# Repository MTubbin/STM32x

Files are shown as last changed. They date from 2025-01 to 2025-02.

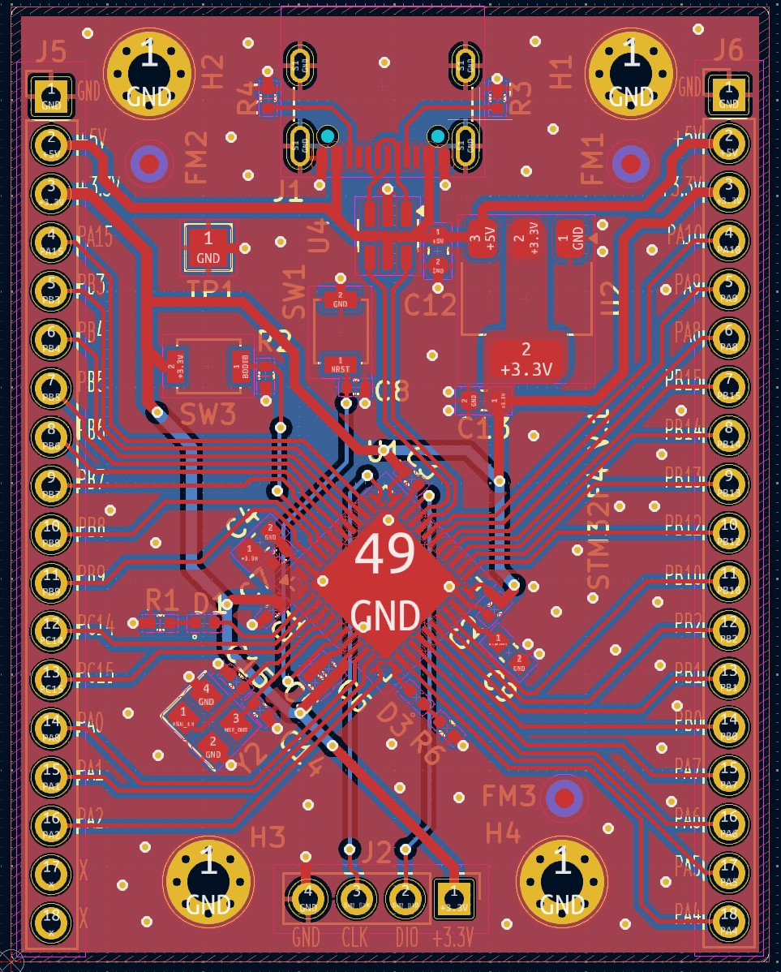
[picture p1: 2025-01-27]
Hardware/Photos/STM32_2Layer.jpg

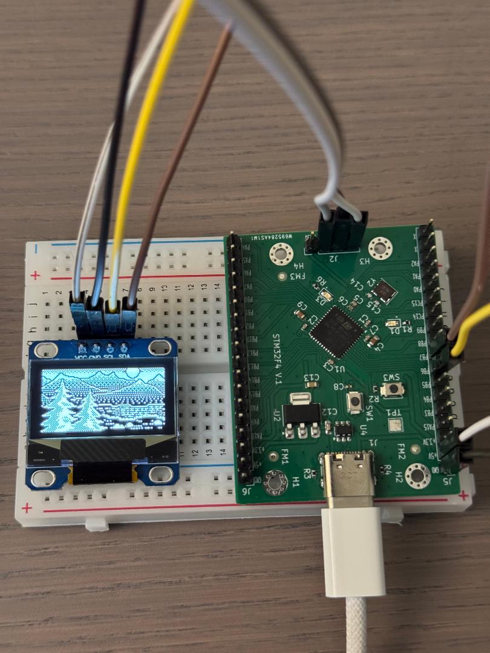
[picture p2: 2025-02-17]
Hardware/Photos/display.jpg

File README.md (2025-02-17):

# STM32x
Repo for custom STM32F4 Breakout board 

Directory:

Hardware folder - PCB Schematic, board layout
  - Photos: Schematic, PCB, and Board Photos

Software folder - current main and display txt files

STM32 Board

display

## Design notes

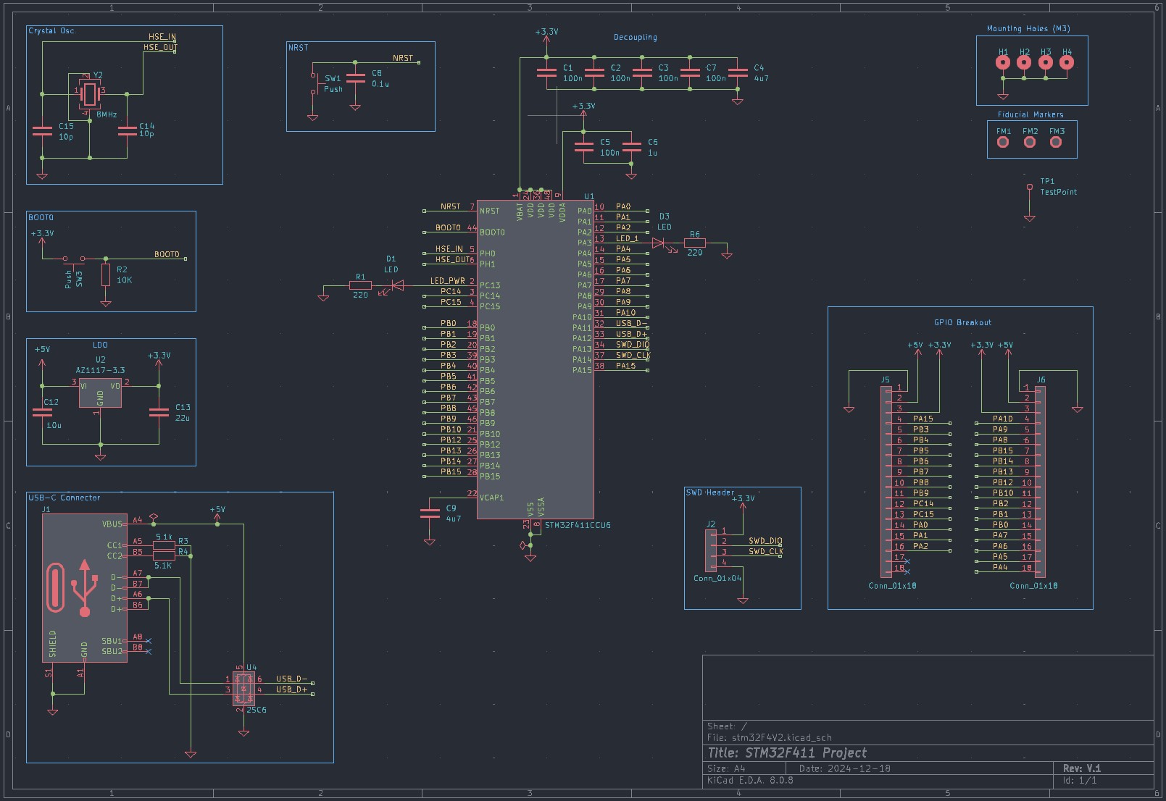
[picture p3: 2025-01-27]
Hardware/Photos/STM32_Schematic.jpg

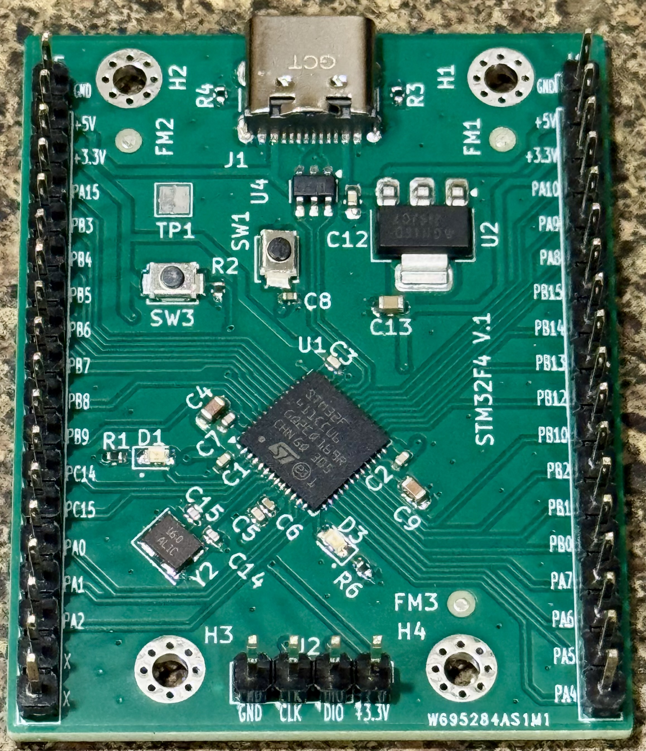
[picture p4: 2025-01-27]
Hardware/Photos/STM32 Board.jpg

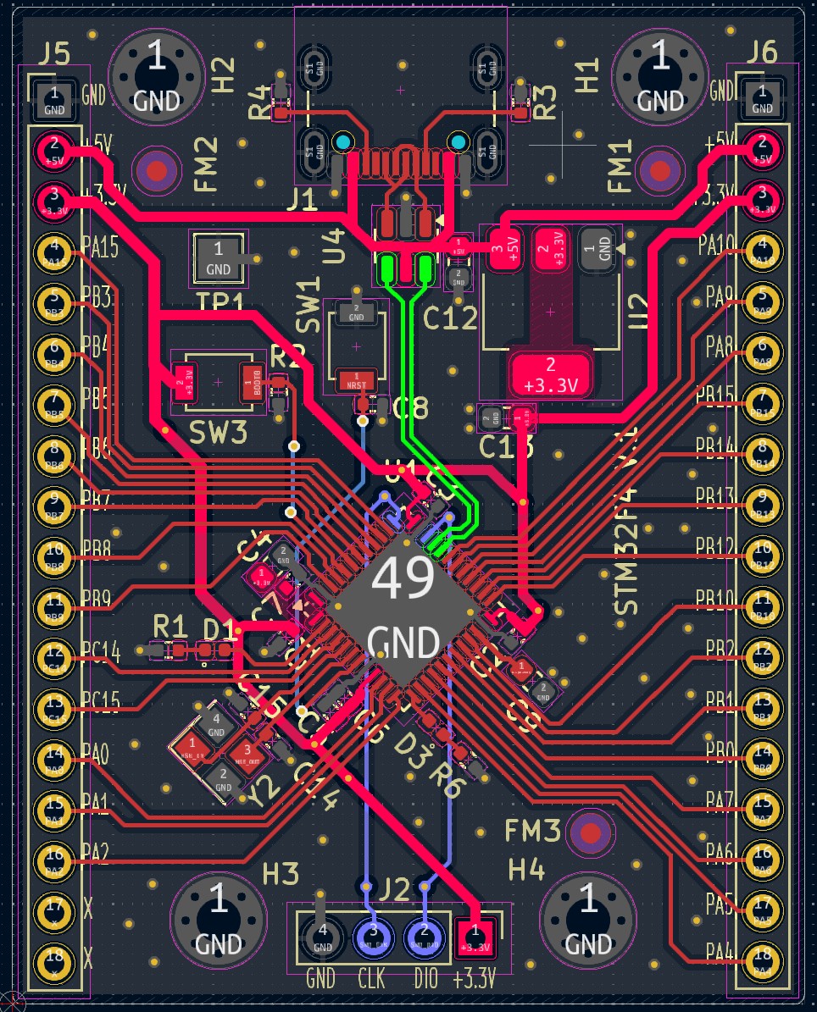
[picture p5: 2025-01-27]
Hardware/Photos/STM32_PCB.jpg

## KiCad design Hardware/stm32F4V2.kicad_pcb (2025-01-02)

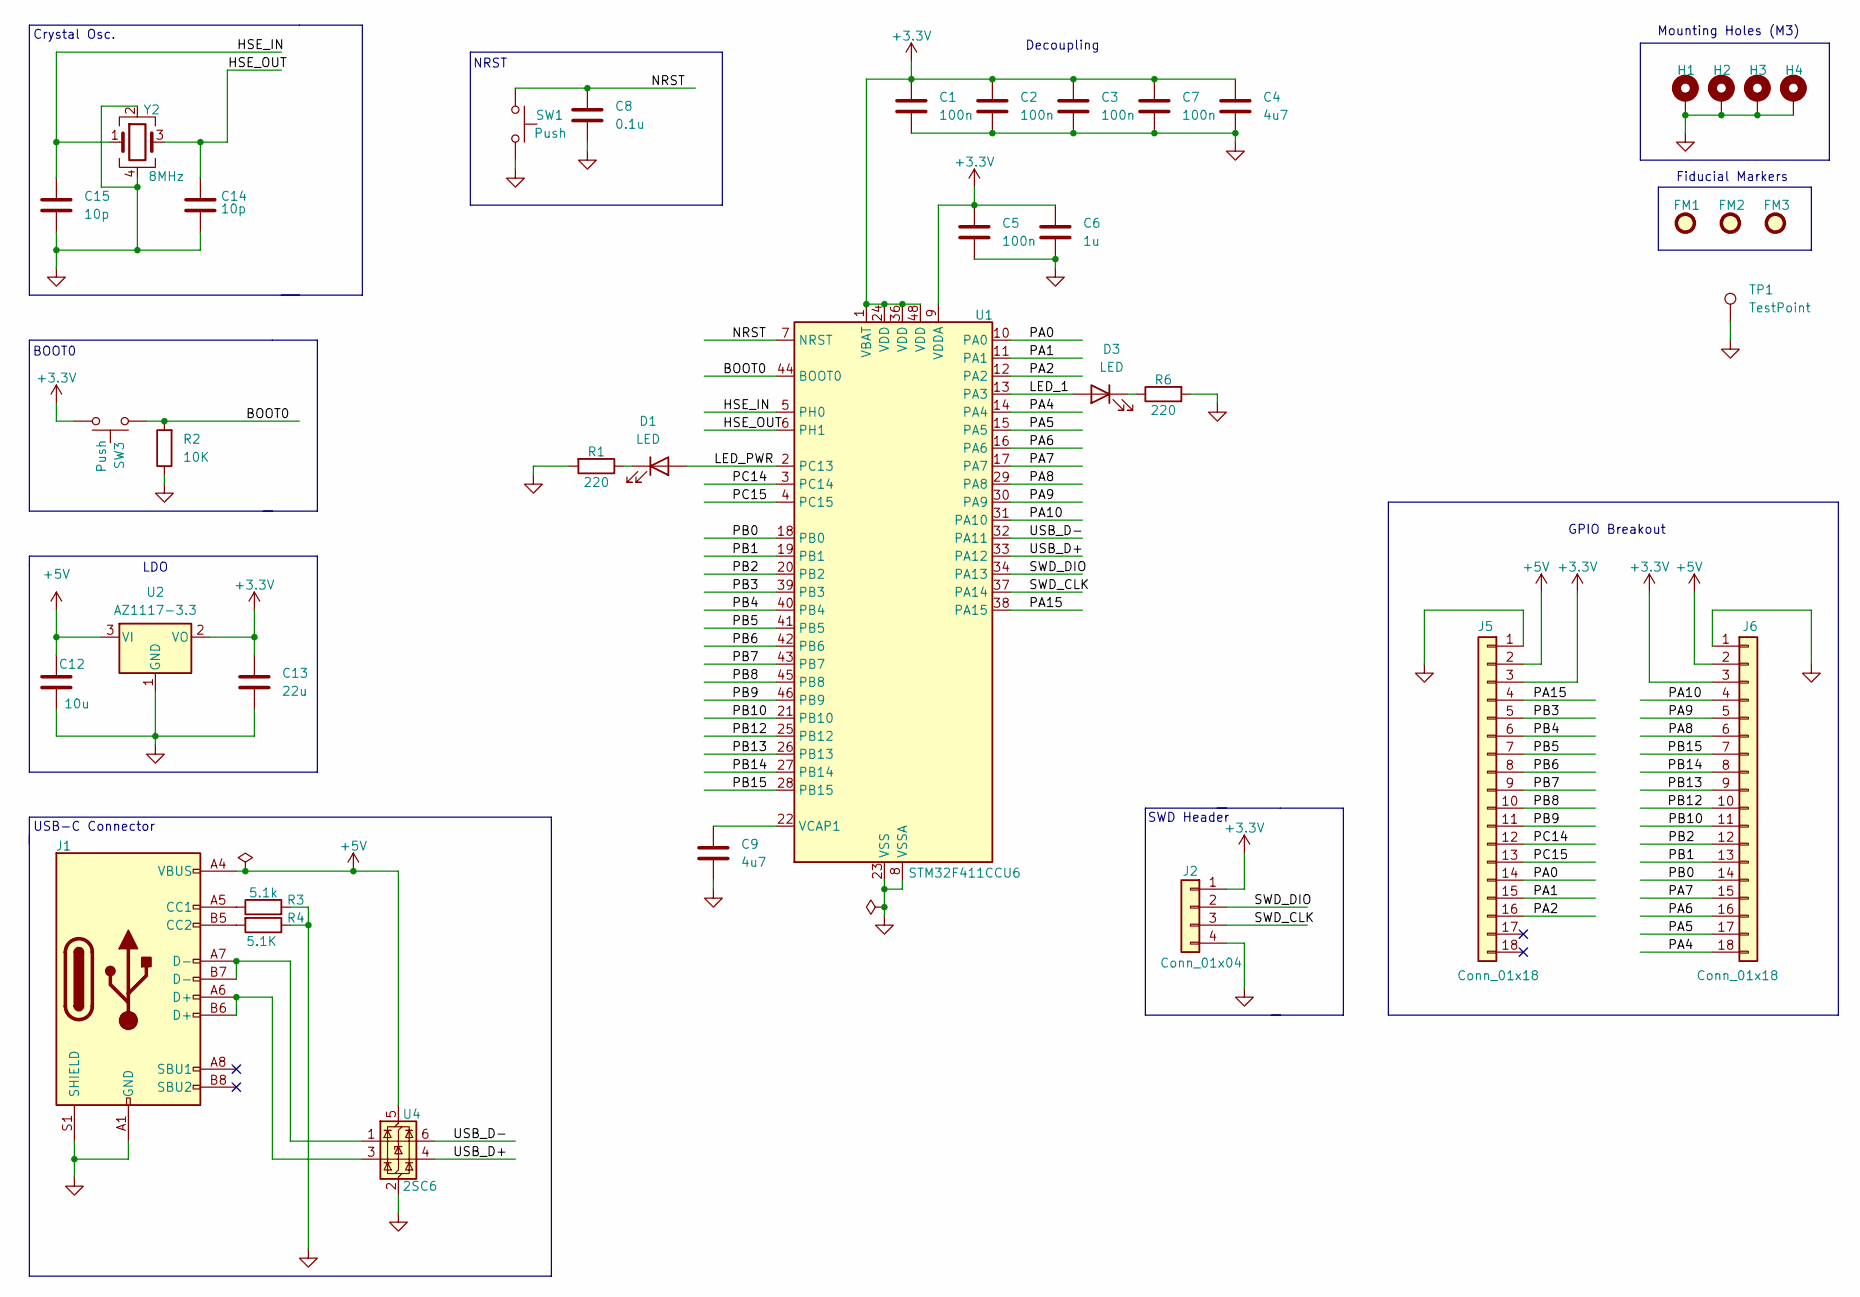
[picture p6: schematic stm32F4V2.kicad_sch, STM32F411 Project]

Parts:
C1, C2, C3, C5, C7: 100n; C_0402_1005Metric; Manufacturer Part Number 04023C104KAT2A-62
C4, C9: 4u7; C_0603_1608Metric; Manufacturer Part Number C1608X5R1C475K080AC
C6: 1u; C_0402_1005Metric; Manufacturer Part Number GRM155R70J105KA12D
C8: 0.1u; C_0402_1005Metric; Manufacturer Part Number 0402B104K160HI
C12: 10u; C_0603_1608Metric; Manufacturer Part Number CL10A106MQ8NNNC
C13: 22u; C_0603_1608Metric; Manufacturer Part Number GRM188R60J226MEA0D
C14, C15: 10p; C_0402_1005Metric; Manufacturer Part Number 885012005007
D1, D3: LED; LED_0402_1005Metric; Manufacturer Part Number YY0402RE-NN2S0-T1AR4
FM1, FM2, FM3: Fiducial; Fiducial_1mm_Mask2mm
H1, H2, H3, H4: MountingHole_Pad; MountingHole_2.2mm_M2_Pad_Via
J1: USB_C_Receptacle_USB2.0_16P; USB_C_Receptacle_GCT_USB4105-xx-A_16P_TopMnt_Horizontal; Manufacturer Part Number USB4105-GF-A
J2: Conn_01x04; PinHeader_1x04_P2.54mm_Vertical; Manufacturer Part Number 61300411121
J5, J6: Conn_01x18; PinHeader_1x18_P2.54mm_Vertical; Manufacturer Part Number PH1-18-UA
R1, R6: 220; R_0402_1005Metric; Manufacturer Part Number RC0402FR-07221RL
R2: 10K; R_0402_1005Metric; Manufacturer Part Number RC0402JR-0710KL
R3: 5.1k; R_0402_1005Metric; Manufacturer Part Number RC0402FR-075K1L
R4: 5.1K; R_0402_1005Metric; Manufacturer Part Number RC0402FR-075K1L
SW1, SW3: Push; SW_SPST_B3U-1000P; Manufacturer Part Number B3U-1000P-B
TP1: TestPoint; TestPoint_Pad_2.0x2.0mm
U1: STM32F411CCU6; QFN-48-1EP_7x7mm_P0.5mm_EP5.6x5.6mm; Manufacturer Part Number STM32F411CCU6TR
U2: AZ1117-3.3; SOT-223-3_TabPin2; Manufacturer Part Number AZ1117CH-3.3TRG1
U4: 2SC6; SOT-23-6; Manufacturer Part Number USBLC6-2SC6
Y2: 8MHz; Crystal_SMD_Abracon_ABM8G-4Pin_3.2x2.5mm; Manufacturer Part Number ABM8G-16.000MHZ-4Y-T3

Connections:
+3.3V: C1.1, C2.1, C3.1, C4.1, C5.1, C6.1, C7.1, C13.1, J2.1, J5.3, J6.3, SW3.2, U1.1 (VBAT), U1.9 (VDDA), U1.24 (VDD), U1.36 (VDD), U1.48 (VDD), U2.2 (VO)
+5V: C12.1, J1.A4 (VBUS), J1.A9 (VBUS), J1.B4 (VBUS), J1.B9 (VBUS), J5.2, J6.2, U2.3 (VI), U4.5 (VBUS)
/BOOT0: R2.2, SW3.1, U1.44 (BOOT0)
/HSE_IN: C15.1, U1.5 (PH0), Y2.1
/HSE_OUT: C14.1, U1.6 (PH1), Y2.3
/LED_1: D3.2 (A), U1.13 (PA3)
/LED_PWR: D1.2 (A), U1.2 (PC13)
/NRST: C8.2, SW1.1, U1.7 (NRST)
/PA0: J5.14, U1.10 (PA0)
/PA1: J5.15, U1.11 (PA1)
/PA2: J5.16, U1.12 (PA2)
/PA4: J6.18, U1.14 (PA4)
/PA5: J6.17, U1.15 (PA5)
/PA6: J6.16, U1.16 (PA6)
/PA7: J6.15, U1.17 (PA7)
/PA8: J6.6, U1.29 (PA8)
/PA9: J6.5, U1.30 (PA9)
/PA10: J6.4, U1.31 (PA10)
/PA15: J5.4, U1.38 (PA15)
/PB0: J6.14, U1.18 (PB0)
/PB1: J6.13, U1.19 (PB1)
/PB2: J6.12, U1.20 (PB2)
/PB3: J5.5, U1.39 (PB3)
/PB4: J5.6, U1.40 (PB4)
/PB5: J5.7, U1.41 (PB5)
/PB6: J5.8, U1.42 (PB6)
/PB7: J5.9, U1.43 (PB7)
/PB8: J5.10, U1.45 (PB8)
/PB9: J5.11, U1.46 (PB9)
/PB10: J6.11, U1.21 (PB10)
/PB12: J6.10, U1.25 (PB12)
/PB13: J6.9, U1.26 (PB13)
/PB14: J6.8, U1.27 (PB14)
/PB15: J6.7, U1.28 (PB15)
/PC14: J5.12, U1.3 (PC14)
/PC15: J5.13, U1.4 (PC15)
/SWD_CLK: J2.3, U1.37 (PA14)
/SWD_DIO: J2.2, U1.34 (PA13)
/USB_D+: U1.33 (PA12), U4.4 (I/O2)
/USB_D-: U1.32 (PA11), U4.6 (I/O1)
GND: C1.2, C2.2, C3.2, C4.2, C5.2, C6.2, C7.2, C8.1, C9.2, C12.2, C13.2, C14.2, C15.2, H1.1, H2.1, H3.1, H4.1, J1.A1 (GND), J1.A12 (GND), J1.B1 (GND), J1.B12 (GND), J1.S1 (SHIELD), J2.4, J5.1, J6.1, R1.2, R2.1, R3.2, R4.1, R6.2, SW1.2, TP1.1, U1.8 (VSSA), U1.23 (VSS), U1.35 (VSS), U1.47 (VSS), U1.49 (VSS), U2.1 (GND), U4.2 (GND), Y2.2, Y2.4
unnamed: D1.1 (K), R1.1
unnamed: D3.1 (K), R6.1
unnamed: J1.A5 (CC1), R3.1
unnamed: J1.B5 (CC2), R4.2
unnamed: J1.A6 (D+), J1.B6 (D+), U4.3 (I/O2)
unnamed: J1.A7 (D-), J1.B7 (D-), U4.1 (I/O1)
unnamed: C9.1, U1.22 (VCAP1)

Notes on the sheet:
USB-C Connector
NRST
BOOT0
Crystal Osc.
Decoupling
LDO
Mounting Holes (M3)
GPIO Breakout
Fiducial Markers
SWD Header

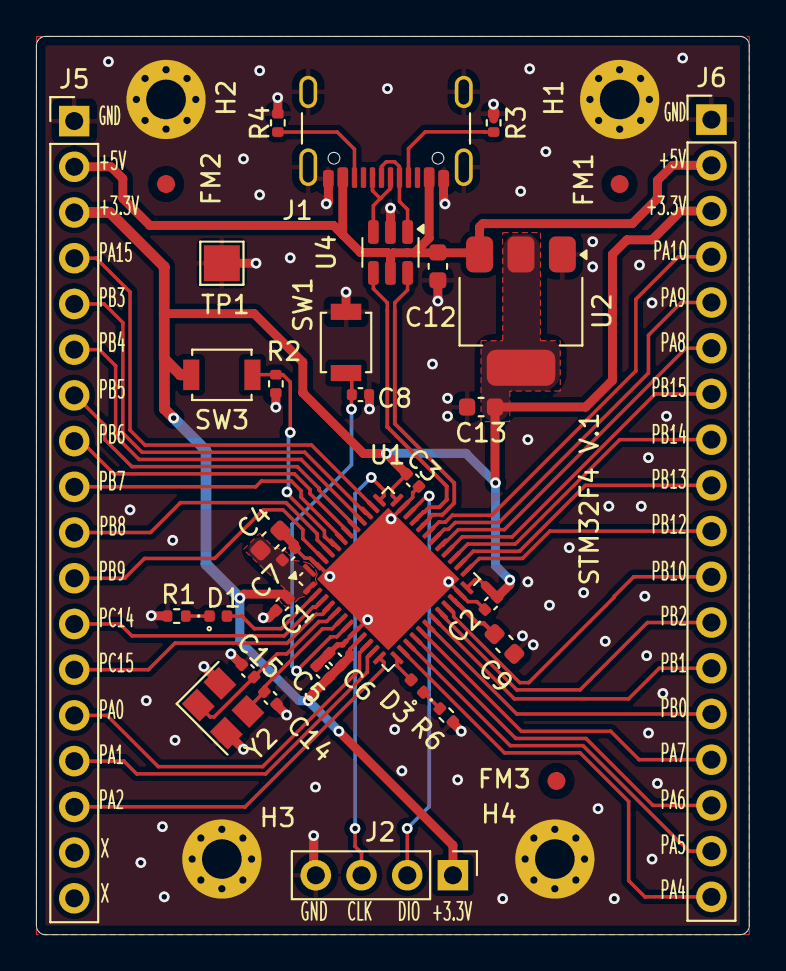
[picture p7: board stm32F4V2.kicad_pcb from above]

Board: 2 copper layers, 39.6 x 49.9 mm, 38 parts (0 on the bottom side), 48 nets.

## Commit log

2024-12-17 Added KiCad files with initial development
    [stm32F4.kicad_pcb, stm32F4.kicad_sch]
2024-12-19 Added GPIO Breakout and SWD Conn.
    [stm32F4.kicad_sch]
2024-12-24 Added Footprints and Parts list
    [stm32F4.kicad_sch]
2024-12-25 Added Initial PCB Layout
    [stm32F4.kicad_pcb]
2024-12-25 Added Net Labels and refined Footprints
    [stm32F4.kicad_sch]
2024-12-30 PCB Layout Rough Draft and Schematic Changes
    [stm32F4.kicad_pcb, stm32F4.kicad_sch]
2025-01-01 Revised board layout
    [stm32F4V2.kicad_pcb, stm32F4V2.kicad_sch]
2025-01-02 Finalized Layout for V.1
    [stm32F4.kicad_pcb, stm32F4.kicad_sch, stm32F4V2.kicad_pcb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]
2025-01-27 Added Board and Schematic Photos
2025-02-17 Added current software
